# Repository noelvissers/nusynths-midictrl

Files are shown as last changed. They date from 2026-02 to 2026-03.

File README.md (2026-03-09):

# NU Synths | MIDICTRL

Firmware for the NU Synths 'MIDICTRL' eurorack module. Converts MIDI signals (5 pin MIDI or MIDI-USB) to eurorack compatible control voltage (CV) and gate signals.

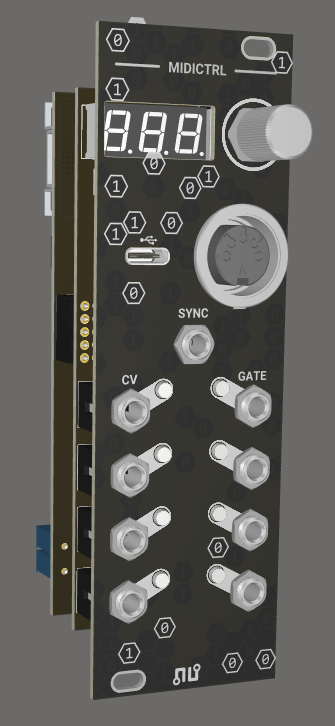
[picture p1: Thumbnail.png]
nusynths-midictrl-thumbnail


For hardware design see [nusynths-midictrl-hardware](https://github.com/noelvissers/nusynths-midictrl-hardware) repository.

## Contents

The following files and folders are in this repository:

|File / Folder |Remarks
|---|---
|.boards/ |Custom board files
|.variants/ |Custom variant files
|.vscode/ |VS Code settings
|include/ |Header (.h) files
|lib/ |Custom libraries
|src/ |Source (.cpp) files
|test/ |Test files
|LICENSE |-
|README.md |-
|platformio.ini|-

## Documentation

### General settings

To access the settings, hold the rotary encoder button for 1 second.

Select by pressing the rotary button, go back by holding the button.

|Setting |Remarks
|---|---
|MIDI channel  |MIDI channel to listen to (All, 1 to 16)
|Synth mode |Monophonic or polyphonic mode (see below)
|Pitch bend |Range of the pitch bend wheel (0 to 12 semitones)
|Cock division |MIDI clock divider amount (1 for 1:1, /2 to /128)

### Synth mode

#### Monophonic

In monophonic mode the pitch, velocity and gate are mapped to all outputs that are assigned this function. When two or more notes are played at the same time, the latest pressed note will be used to overwrite the previous one. When the latest pressed note is released, the CV value will **not** go back to the previous value, if that note is not released yet.

#### Polyphonic

In polyphonic mode the pitch, velocity and gate are mapped sequentially to the first available output. When two or more notes are played at the same time, the latest pressed note will **not** overwrite the previous one(s) when no outputs are available.

### Output functions

Each output can be configured to a certain function via the configuration menu:

|Function |Supported outputs |Remarks
|---|---|---
|Clock |SYNC |MIDI sync (1:1 to /128)
|Pitch |CV |1V/Oct (0-10V)
|Velocity |CV |0-10V
|CC + MIDI learn |CV |0-10V
|Aftertouch |CV |0-10V
|Gate |CV + GATE |0-5V
|Trigger + MIDI learn* |CV + GATE |0-5V, 1ms
|Reset |CV + GATE |0-5V, 1ms

\* Optional (press rotary encoder to cancel)

Analog (CV) outputs will be updated before digital (GATE) outputs, meaning pitch/velocity will be updated on the output before a gate or trigger signal. When mapping gate or trigger to a DAC output, make sure to be aware of this behaviour.

### Menu structure

```txt
Menu
├─ Settings
│  ├─ Midi channel
│  │  ├─ All
│  │  ├─ 1
│  │  ├─ ...
│  │  └─ 16
│  ├─ Mode
│  │  ├─ Monophonic
│  │  └─ Polyphonic
│  ├─ Pitch bend
│  │  ├─ 0 semitones
│  │  ├─ ...
│  │  └─ 12 semitones
│  └─ Clock division
│     ├─ 1:0
│     ├─ /2
│     ├─ ...
│     └─ /128
├─ Output (CV [1..4])
│  ├─ Pitch
│  ├─ Velocity
│  ├─ CC → Learn MIDI CC [Required]
│  ├─ Aftertouch
│  ├─ Gate
│  ├─ Trigger → Learn MIDI note [Optional]
│  ├─ Reset
│  └─ Unassigned
└─ Output (Gates [5..8])
   ├─ Gate
   ├─ Trigger → Learn MIDI note [Optional]
   ├─ Reset
   └─ Unassigned
```

## Usage

Open the project in [Visual Studio Code](https://code.visualstudio.com/) with the [PlatformIO](https://platformio.org/) extension installed.

This code uses a custom board file that can be found in the .boards folder. This file should be placed in the `.platformio\platforms\atmelsam\boards` folder.

This code uses a custom variant.cpp/.h file that can be found in the .variants folder. This folder (mkrzero_nu_midictrl) should be placed in the `.platformio\packages\framework-arduino-samd\variants\mkrzero_nu_midictrl` folder. This variant is needed since a custom Serial1 is defined, since MIDI (RX) is routed to PA22 instead of PB23.

## Dependencies

[fortyseveneffects/MIDI Library](https://github.com/FortySevenEffects/arduino_midi_library) [v5.0.2]

[arduino-libraries/MIDIUSB](https://github.com/arduino-libraries/MIDIUSB) [v1.0.5]

[khoih-prog/FlashStorage_SAMD](https://github.com/khoih-prog/FlashStorage_SAMD) [v1.3.2]

## Release Notes

### [1.0.2]

* Feature: Button press will toggle display which can be usefull to reduce noise made by the LED driver
* Feature: Show firmware version on startup

### [1.0.1]

* Bugfix: Map gate correctly in poly mode
* Bugfix: Update outputs correctly when changed during active state

### [1.0.0]

* Initial release

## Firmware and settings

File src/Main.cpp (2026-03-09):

#include <Arduino.h>

#include "HalConfiguration.h"
#include "MidiHandler.h"
#include "Gui.h"
#include "Menu.h"
#include "Settings.h"
#include "Outputs.h"

CSettings settings;
CGui gui(_pinDisplaySs, _pinDisplaySck, _pinDisplayMosi);
COutputs outputs(gui);
CMidiHandler midiHandler(outputs, settings, gui);
CMenu menu(gui, settings, midiHandler);

static volatile unsigned long lastTrig = 0;
static volatile bool stateLast = 0;
void isrRotaryEncorder()
{
  unsigned long now = millis();
  if (now - lastTrig < 5)
    return; // Debounce

  bool rotaryEncClk = (*_portRotaryEncClk & _maskRotaryEncClk) != 0;
  bool rotaryEncData = (*_portRotaryEncData & _maskRotaryEncData) != 0;

  if (rotaryEncClk == stateLast)
    return; // No change

  if (!rotaryEncClk)
  {
    if (rotaryEncClk == rotaryEncData)
      _flagRotaryEncCw = true;
    else
      _flagRotaryEncCcw = true;
  }
  lastTrig = now;
  stateLast = rotaryEncClk;
}

unsigned long rotaryEncButtonLast = 0;
void isrRotaryEncButton()
{
  // Read BUTTON pin
  bool rotaryEncButton = (*_portRotaryEncButton & _maskRotaryEncButton) != 0;
  if (!rotaryEncButton)
  {
    _flagRotaryEncButton = true;
    rotaryEncButtonLast = millis();
  }
  else
    _flagRotaryEncButton = false;
}

// Setup
void setup()
{
  Serial.begin(115200);

  // ISR Rotarty Encoder Button
  pinMode(_pinRotaryEncButton, INPUT);
  _maskRotaryEncButton = digitalPinToBitMask(_pinRotaryEncButton);
  _portRotaryEncButton = portInputRegister(digitalPinToPort(_pinRotaryEncButton));
  attachInterrupt(digitalPinToInterrupt(_pinRotaryEncButton), isrRotaryEncButton, CHANGE);

  // ISR Rotarty Encoder Clk
  pinMode(_pinRotaryEncClk, INPUT);
  _maskRotaryEncClk = digitalPinToBitMask(_pinRotaryEncClk);
  _portRotaryEncClk = portInputRegister(digitalPinToPort(_pinRotaryEncClk));
  attachInterrupt(digitalPinToInterrupt(_pinRotaryEncClk), isrRotaryEncorder, CHANGE);

  // ISR Rotarty Encoder Data
  pinMode(_pinRotaryEncData, INPUT);
  _maskRotaryEncData = digitalPinToBitMask(_pinRotaryEncData);
  _portRotaryEncData = portInputRegister(digitalPinToPort(_pinRotaryEncData));
  attachInterrupt(digitalPinToInterrupt(_pinRotaryEncData), isrRotaryEncorder, CHANGE);

  // LED
  pinMode(LED_BUILTIN, OUTPUT);
  digitalWrite(LED_BUILTIN, HIGH); // Turn on LED

  outputs.init();

  // Show startup animation
  gui.setString("1.0.2");
  delay(1000);
  gui.startup();

  // Load saved configuration from flash (or default when no settings found)
  settings.load();
  outputs.setOutputs(settings.get());

  midiHandler.begin();

  // Show idle state
  delay(1000);
  gui.active();
}

// Main
bool buttonPress = false;
void loop()
{
  if (_flagRotaryEncButton && !buttonPress)
    buttonPress = true;

  if (_flagRotaryEncButton && ((millis() - rotaryEncButtonLast >= 1000)))
  {
    gui.setActive(true);
    menu.start();
    while (menu.active())
    {
      menu.display();
      menu.update(_flagRotaryEncCw, _flagRotaryEncCcw, _flagRotaryEncButton);
    }
    settings.save();
    outputs.setOutputs(settings.get());
    midiHandler.readAndFlush();
    outputs.reset();
    rotaryEncButtonLast = millis(); // Make sure that menu is not immediately reopened
    gui.clear();
    gui.active();
    while (_flagRotaryEncButton)
      ;
    buttonPress = false;
  }
  else if (buttonPress && !_flagRotaryEncButton)
  {
    gui.clear();
    if (gui.getActive())
      gui.setActive(false);
    else
    {
      gui.setActive(true);
      gui.active();
    }
    buttonPress = false;
  }
  midiHandler.read();
  outputs.update();
}

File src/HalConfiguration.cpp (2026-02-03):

#include "HalConfiguration.h"
#include <Arduino.h>
#include <cstdint>

// Rotary encoder
const uint8_t _pinRotaryEncButton = 5; // PB11
const uint8_t _pinRotaryEncClk = 1;    // PA23
const uint8_t _pinRotaryEncData = 4;   // PB10

// Rotary encoder port and bit masks for faster IO read/writes
uint32_t _maskRotaryEncButton = 0;                 // Value set in setup()
volatile uint32_t *_portRotaryEncButton = nullptr; // Value set in setup()
uint32_t _maskRotaryEncClk = 0;                    // Value set in setup()
volatile uint32_t *_portRotaryEncClk = nullptr;    // Value set in setup()
uint32_t _maskRotaryEncData = 0;                   // Value set in setup()
volatile uint32_t *_portRotaryEncData = nullptr;   // Value set in setup()

// Rotary encoder flags
volatile bool _flagRotaryEncButton = false;
volatile bool _flagRotaryEncCw = false;
volatile bool _flagRotaryEncCcw = false;

// Gates [5V DIO]
const uint8_t _pinGate1 = 16; // PB02
const uint8_t _pinGate2 = 17; // PB03
const uint8_t _pinGate3 = 18; // PA04
const uint8_t _pinGate4 = 19; // PA05

// Sync [5V DIO]
const uint8_t _pinSync = 20; // PA06

// SPI
const uint32_t _spiSpeed = 24000000; // 24 MHz (Maximum SPI speed for MKRZero)

// DAC8564
const uint8_t _pinDacSync = 7;   // PA21
const uint8_t _pinDacLdac = 11;  // PA08
const uint8_t _pinDacEnable = 6; // PA20
// const uint8_t _pinDacMosi = 8; // PA16
// const uint8_t _pinDacMiso = 10; // PA19
// const uint8_t _pinDacSck = 9; // PA17

const uint8_t _pinDisplaySs = 21;  // PA07
const uint8_t _pinDisplaySck = 3;  // PA11
const uint8_t _pinDisplayMosi = 2; // PA10

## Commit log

2025-05-06 Commit PlatformIO default Arduino MKRZERO project
2025-08-04 Add MIDI channel filter
2025-08-05 Add files so names are correct again
    [Gui.cpp, Main.cpp, MidiHandler.cpp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]
2025-08-06 Add midi channel filtering
2025-08-06 Fix pitch noteOff
2025-09-23 Add string printing to GUI
2025-09-30 Output LED implementation
2025-10-01 Add custom board
2025-11-02 Encoder fixes
2025-11-17 Fix led values in menu
2025-11-18 Implement getting current setting for showing menu
2025-11-18 update board variant files
    [arduino_zero.cfg]
2025-11-18 update board config
2026-02-03 Add schematic
2026-02-03 Update hwids (use arduino default for bootloader, custom for firmware)
2026-02-12 Add Altium source files
    [ControlVoltage.SchDoc, Microcontroller.SchDoc, Midi.SchDoc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]
2026-02-21 Move hardware files to standalone different repository
    [ControlVoltage.SchDoc, Microcontroller.SchDoc, Midi.SchDoc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]
2026-02-28 Fix GUI reset after save
    [Gui.cpp, Main.cpp]
2026-02-28 Fix midi handler bugs
    [MidiHandler.cpp, Outputs.cpp]
2026-02-28 Led based on active, not value
2026-02-28 Better LED handling
2026-03-01 Update output led on noteoff
2026-03-04 Reset outputs on change
    [Main.cpp, Outputs.cpp, Outputs.h]
2026-03-04 Fix overwriting gates in poly mode
    [MidiHandler.cpp]
2026-03-08 Button press will toggle display/leds
